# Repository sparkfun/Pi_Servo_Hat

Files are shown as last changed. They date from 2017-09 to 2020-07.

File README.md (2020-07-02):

SparkFun Pi Servo pHAT
=====================

Pi Servo pHAT (https://cdn.sparkfun.com/assets/parts/1/3/8/2/7/15316-SparkFun_Servo_pHAT_for_Raspberry_Pi-01.jpg)

[SparkFun Servo pHAT for Raspberry Pi (DEV-15316)](https://www.sparkfun.com/products/15316)

<!--
<table class="table table-hover table-striped table-bordered">
  <tr align="center">
   <td><a href="https://www.sparkfun.com/products/14328"><img src="https://cdn.sparkfun.com/r/600-600/assets/parts/1/2/3/0/2/14328-01.jpg" alt="Pi Servo Hat"></a></td>
   <td><a href="https://www.sparkfun.com/products/14329"><img src="https://cdn.sparkfun.com/r/600-600/assets/parts/1/2/3/0/3/Pi-Cam_Kit_14329-_01.jpg" alt="SparkFun Raspberry Pi Zero W Camera Kit"></a></td>
  </tr>
  <tr align="center">
    <td><i>Pi Servo Hat [<a href="https://www.sparkfun.com/products/14328">DEV-14328</a>]</i></td>
    <td><i>SparkFun Raspberry Pi Zero W Camera Kit [<a href="https://www.sparkfun.com/products/14329">KIT-14329</a>]</i></td>
  </tr>
</table>
-->

The Pi Servo pHAT is a hat that adds, via I<sup>2</sup>C, the ability to control up to 16 servo motors with a Raspberry Pi. It is the same size and form factor as a Pi Zero or Pi Zero W. The Pi Servo pHAT is great for adding pan/tilt control with the Raspberry Pi Camera to create homemade motion-activated security systems, webcam interfaces for streaming, or monitoring stations for any number of projects and adventures. 

Repository Contents
-------------------
* **/Hardware** - All Eagle design files (.brd, .sch)
* **/Examples** - All Python examples for this board
* **/Production** - Test bed files and production panel files

Documentation
--------------
* **[Hookup Guide](https://learn.sparkfun.com/tutorials/pi-servo-phat-v2-hookup-guide)** - Basic hookup guide for the Pi Servo pHAT.
* **[Setting Up the Pi Zero Wireless Pan-Tilt Camera](https://learn.sparkfun.com/tutorials/setting-up-the-pi-zero-wireless-pan-tilt-camera)** - Pi Zero Wireless Pan-Tilt Camera Kit Assembly Guide (*can be used with the Pi Servo pHAT*). 

Product Versions
--------------
* [SparkFun Pi Servo HAT (DEV-14328)](https://www.sparkfun.com/products/14328) - Original product release.
* [SparkFun Pi Servo pHAT for Raspberry Pi (DEV-15316)](https://www.sparkfun.com/products/15316)- Updated USB-to-serial converter (CH340C) and USB-C connector, corrected to Pi HAT form factor, added QWiic connector and reverse current protection, provides 4-pin header for compatibility with Sphero RVR, and comes with pre-soldered female 40-pin GPIO header.

License Information
-------------------

This product is _**open source**_! 

Please review the LICENSE.md file for license information. 

If you have any questions or concerns on licensing, please visit the [SparkFun Forum](https://forum.sparkfun.com/index.php) and post a topic. <!--For more general questions related to our Raspberry Pi hats, please visit this section of the forum: [SparkFun Forums: Raspberry Pi Products](https://forum.sparkfun.com/viewforum.php?f=105)-->

Distributed as-is; no warranty is given.

- Your friends at SparkFun.

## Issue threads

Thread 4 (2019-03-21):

More than 16 servo motors

Neorichi, 2019-03-21:
Hi,
Thanks for this project but i am interesting about get more than 16 servo motors... could you help me?

Thanks a lot

edspark, 2019-03-21:
Hello!

This isn't an "issue" in the way Github issues are intended to be used. However, this is a great topic to bring up in the robotics page of our forums:

https://forum.sparkfun.com/viewforum.php?f=107&sid=6486982292d4ee408e5b5e12ff93be67

Closed 2019-03-21.

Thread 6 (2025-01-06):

Voltage levels

mrherman, 2025-01-06:
I haven't tried this hat yet, but confused how it is wired up.  The schematic shows the PCA9685 being powered from the 5V signal, but it then expects a 0.7 Vdd voltage or higher for the I2C.  Table 14 of the data sheet.  That is 3.5V, but the I2C line of the Pi is a 3.3V logic level.

Is this really powered via the 5V line?  Any issues with I2C not working periodically?

In addition it looks like the address lines are left floating?  The data sheet said they don't have internal pull up resistors on those pins, so they are truly floating?

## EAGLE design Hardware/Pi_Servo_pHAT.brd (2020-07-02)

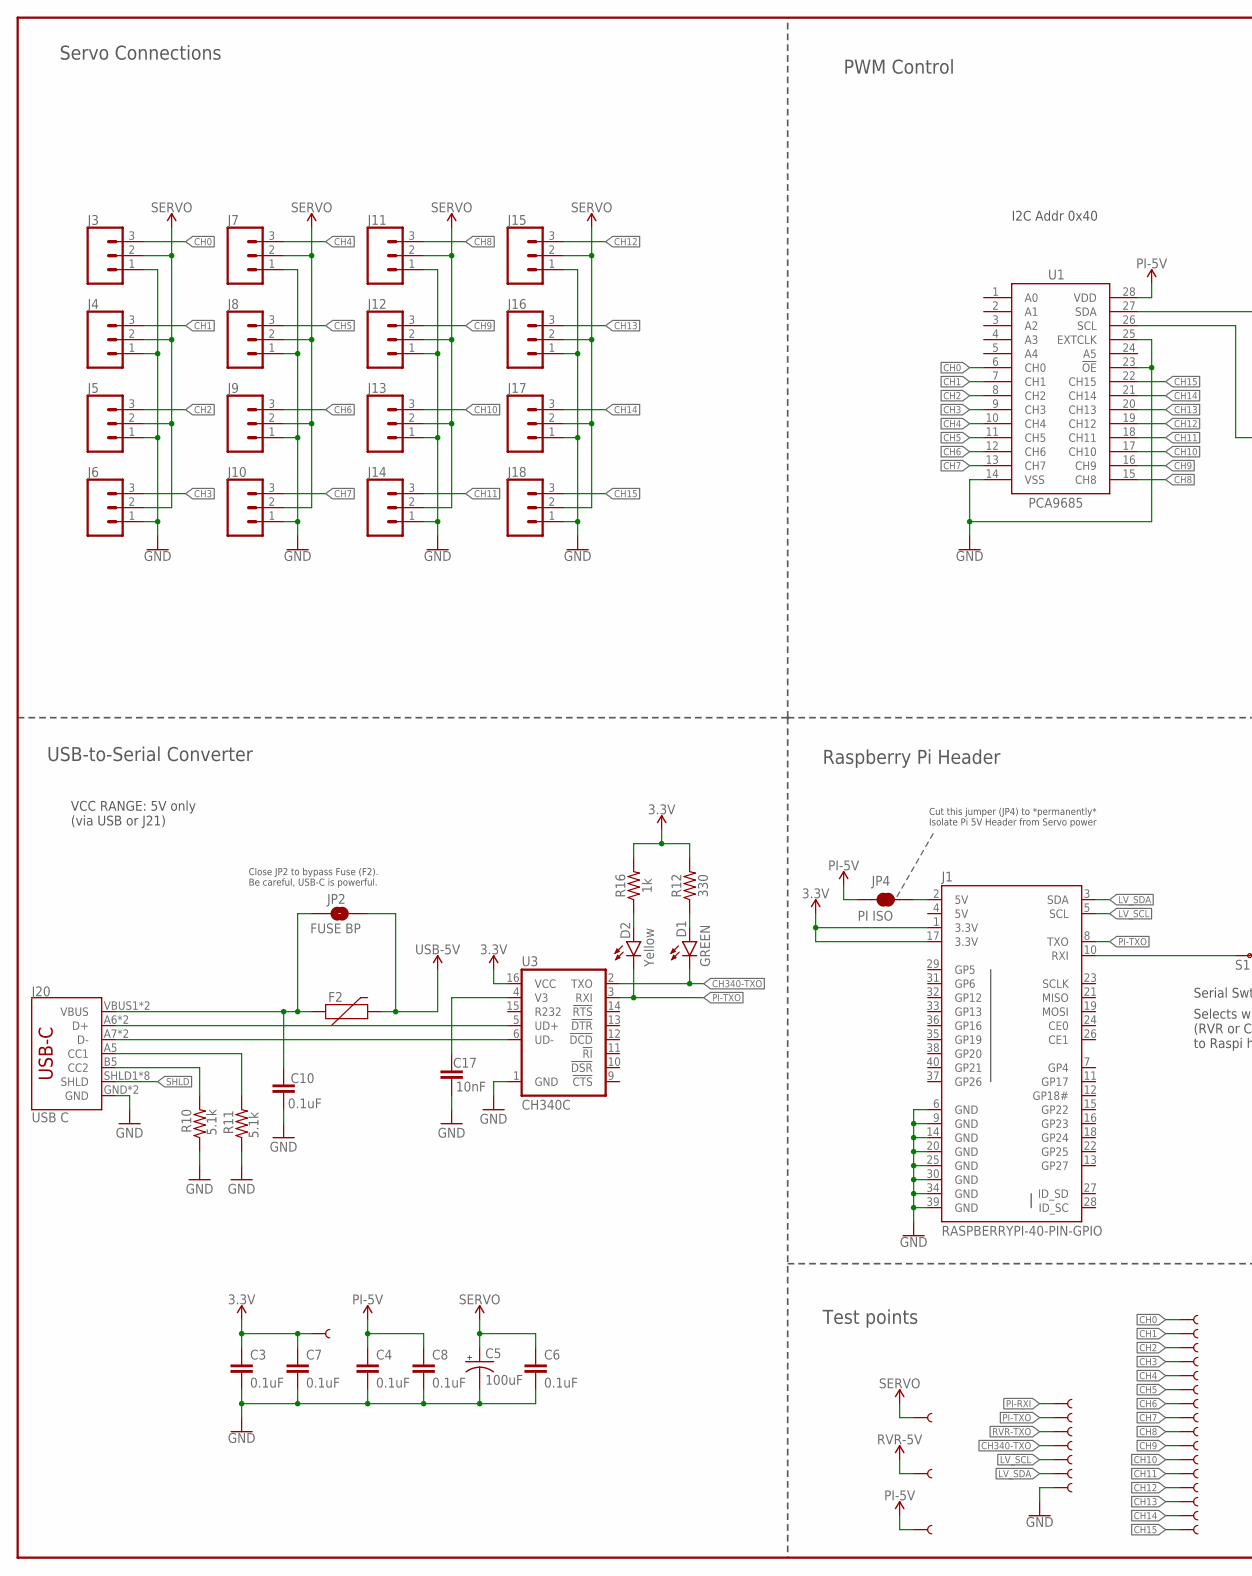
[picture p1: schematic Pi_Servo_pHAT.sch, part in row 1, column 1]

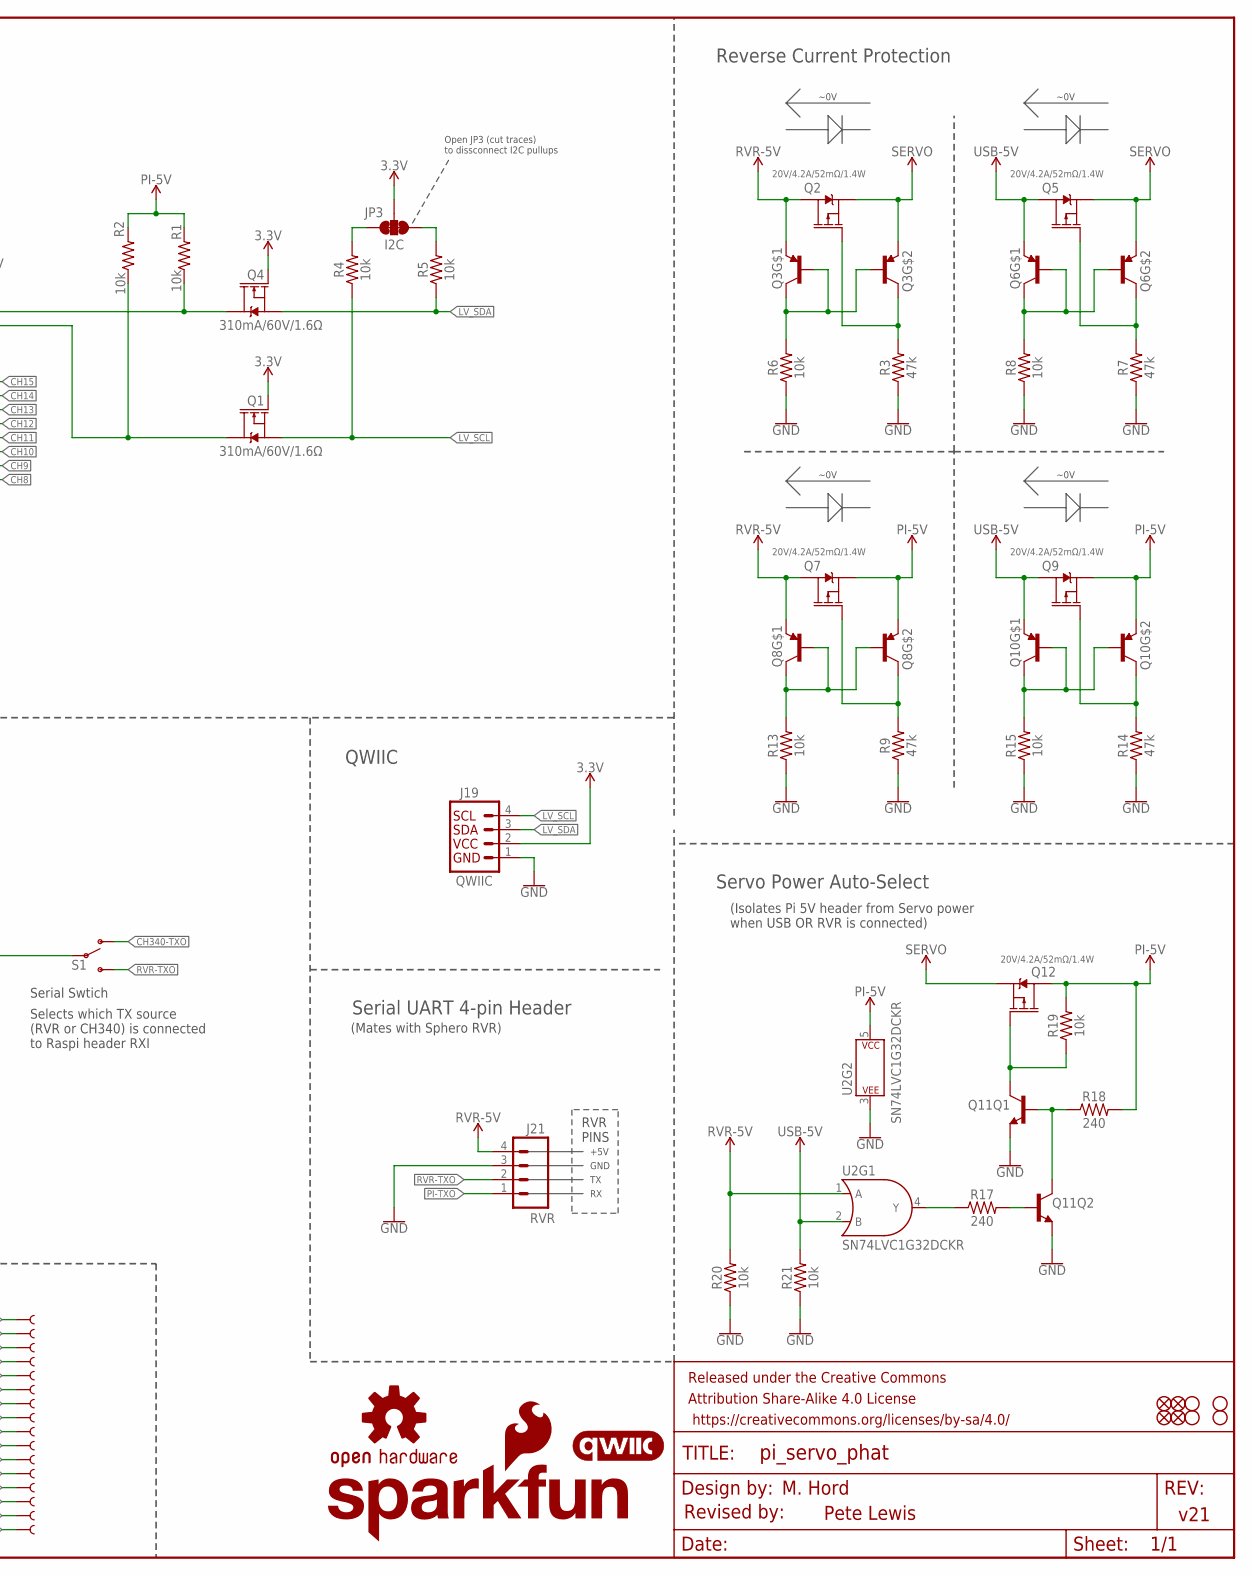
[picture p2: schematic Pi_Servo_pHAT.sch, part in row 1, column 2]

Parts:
C3, C4, C6, C7, C8, C10: 0.1uF; 0603
C5: 100uF; PANASONIC_D
C17: 10nF; 0603
D1: GREEN; LED-0603
D2: Yellow; LED-0603
F2: 16V/2.5A(5A TRIP); 1812
FD1, FD2, FD3, FD4: FIDUCIALUFIDUCIAL; FIDUCIAL-MICRO
FRAME2: FRAME-LEDGER; CREATIVE_COMMONS
H1, H2, H3, H4: STAND-OFF
J1: RASPBERRYPI-40-PIN-GPIO; 2X20
J3, J4, J5, J6, J7, J8, J9, J10, J11, J12, J13, J14, J15, J16, J17, J18: CONN_03; 1X03
J19: QWIIC; JST04_1MM_RA
J20: USB C; USB-C-16P
J21: RVR; 1X04_LOCK
JP2: FUSE BP; SMT-JUMPER_2_NO_SILK
JP3: I2C; SMT-JUMPER_3_2-NC_TRACE_SILK
JP4: PI ISO; SMT-JUMPER_2_NC_TRACE_SILK
LOGO1: SFE_LOGO_NAME_FLAME.1_INCH; SFE_LOGO_NAME_FLAME_.1
LOGO2: OSHW-LOGOS; OSHW-LOGO-S
Q1, Q4: 310mA/60V/1.6Ω; SOT323
Q2, Q5, Q7, Q9, Q12: 20V/4.2A/52mΩ/1.4W; SOT23-3
Q3, Q6, Q8, Q10: TRANS_PNP_DUALSOT-363; SOT363_PHILIPS
Q11: TRANS_NPN_DUAL-MBT3904DW1T1; SC70-6
R1, R2, R4, R5, R6, R8, R13, R15, R19, R20, R21: 10k; 0603
R3, R7, R9, R14: 47k; 0603
R10, R11: 5.1k; 0603
R12: 330; 0603
R16: 1k; 0603
R17, R18: 240; 0603
S1: SWITCH-SPDT-SMD-RIGHT-ANGLE; SWITCH_SPST_SMD_A
TP0, TP1, TP2, TP3, TP4, TP5, TP6, TP7, TP8, TP9, TP10, TP11, TP12, TP13, TP14, TP15, TP16, TP17, TP20, TP21, TP22, TP23, TP24, TP25, TP26: TEST-POINT3X4; PAD.03X.04
TP18, TP19: TEST-POINTTP_15TH_THRU; TP_15TH
U1: PCA9685; TSSOP-28_4MM
U2: SN74LVC1G32DCKR; SOT353
U3: CH340C; SO016
U$1: QWIIC_LOGO_5MM; QWIIC_5MM

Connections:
3.3V: C3.1, C7.1, J1.1 (3.3V), J1.17 (3.3V), J19.2, JP3.2, Q1.1 (G), Q4.1 (G), R12.2, R16.2, TP22.P$1, U3.16 (VCC)
5V: J1.4 (5V)
CC1: J20.A5 (CC1), R11.2
CC2: J20.B5 (CC2), R10.2
CH0: J3.3, TP0.P$1, U1.6 (CH0)
CH1: J4.3, TP1.P$1, U1.7 (CH1)
CH2: J5.3, TP2.P$1, U1.8 (CH2)
CH3: J6.3, TP3.P$1, U1.9 (CH3)
CH4: J7.3, TP4.P$1, U1.10 (CH4)
CH5: J8.3, TP5.P$1, U1.11 (CH5)
CH6: J9.3, TP6.P$1, U1.12 (CH6)
CH7: J10.3, TP7.P$1, U1.13 (CH7)
CH8: J11.3, TP8.P$1, U1.15 (CH8)
CH9: J12.3, TP9.P$1, U1.16 (CH9)
CH10: J13.3, TP10.P$1, U1.17 (CH10)
CH11: J14.3, TP11.P$1, U1.18 (CH11)
CH12: J15.3, TP12.P$1, U1.19 (CH12)
CH13: J16.3, TP13.P$1, U1.20 (CH13)
CH14: J17.3, TP14.P$1, U1.21 (CH14)
CH15: J18.3, TP15.P$1, U1.22 (CH15)
CH340-TXO: D1.C, S1.1 (O), TP23.P$1, U3.2 (TXO)
D+: J20.A6 (D+), J20.B6 (D+), U3.5 (UD+)
D-: J20.A7 (D-), J20.B7 (D-), U3.6 (UD-)
GND: C3.2, C4.2, C5.-, C6.2, C7.2, C8.2, C10.2, C17.2, J1.6 (GND), J1.9 (GND), J1.14 (GND), J1.20 (GND), J1.25 (GND), J1.30 (GND), J1.34 (GND), J1.39 (GND), J3.1, J4.1, J5.1, J6.1, J7.1, J8.1, J9.1, J10.1, J11.1, J12.1, J13.1, J14.1, J15.1, J16.1, J17.1, J18.1, J19.1, J20.GND, J20.GND2 (GND), J21.3, Q11.1 (E), Q11.4 (E), R3.1, R6.1, R7.1, R8.1, R9.1, R10.1, R11.1, R13.1, R14.1, R15.1, R20.1, R21.1, TP17.P$1, U1.14 (VSS), U1.23 (!OE), U1.25 (EXTCLK), U2.3 (P$V-), U3.1 (GND)
LV_SCL: J1.5 (SCL), J19.4, Q1.2 (S), R4.1, TP18.P$1
LV_SDA: J1.3 (SDA), J19.3, Q4.2 (S), R5.1, TP19.P$1
unnamed: Q5.1 (G), Q6.3 (C), R7.2
unnamed: JP3.3, R4.2
unnamed: Q1.3 (D), R2.1, U1.26 (SCL)
unnamed: Q4.3 (D), R1.1, U1.27 (SDA)
unnamed: JP3.1, R5.2
unnamed: D2.A, R16.1
unnamed: D1.A, R12.1
unnamed: Q11.2 (B), R17.2
unnamed: Q2.1 (G), Q3.3 (C), R3.2
unnamed: Q3.2 (B), Q3.5 (B), Q3.6 (C), R6.2
unnamed: Q6.2 (B), Q6.5 (B), Q6.6 (C), R8.2
unnamed: Q11.5 (B), Q11.6 (C), R18.1
unnamed: Q11.3 (C), Q12.1 (G), R19.1
unnamed: C17.1, U3.4 (V3)
unnamed: Q7.1 (G), Q8.3 (C), R9.2
unnamed: Q8.2 (B), Q8.5 (B), Q8.6 (C), R13.2
unnamed: R17.1, U2.4 (Y)
unnamed: Q9.1 (G), Q10.3 (C), R14.2
unnamed: Q10.2 (B), Q10.5 (B), Q10.6 (C), R15.2
unnamed: J1.2 (5V), JP4.2
PI-5V: C4.1, C8.1, JP4.1, Q7.2 (S), Q8.4 (E), Q9.2 (S), Q10.4 (E), Q12.3 (D), R1.2, R2.2, R18.2, R19.2, TP24.P$1, U1.28 (VDD), U2.5 (P$V+)
PI-RXI: J1.10 (RXI), S1.2, TP26.P$1
PI-TXO: D2.C, J1.8 (TXO), J21.1, TP20.P$1, U3.3 (RXI)
RVR-5V: J21.4, Q2.3 (D), Q3.1 (E), Q7.3 (D), Q8.1 (E), R20.2, TP25.P$1, U2.1 (A)
RVR-TXO: J21.2, S1.3 (S), TP21.P$1
SERVO: C5.+, C6.1, J3.2, J4.2, J5.2, J6.2, J7.2, J8.2, J9.2, J10.2, J11.2, J12.2, J13.2, J14.2, J15.2, J16.2, J17.2, J18.2, Q2.2 (S), Q3.4 (E), Q5.2 (S), Q6.4 (E), Q12.2 (S), TP16.P$1
SHLD: J20.SHLD1 (SHLD), J20.SHLD2 (SHLD), J20.SHLD3 (SHLD), J20.SHLD4 (SHLD), J20.SHLD5 (SHLD), J20.SHLD6 (SHLD), J20.SHLD7 (SHLD), J20.SHLD8 (SHLD)
USB-5V: F2.2, JP2.2, Q5.3 (D), Q6.1 (E), Q9.3 (D), Q10.1 (E), R21.2, U2.2 (B)
VBUS: C10.1, F2.1, J20.VBUS1 (VBUS), J20.VBUS2 (VBUS), JP2.1

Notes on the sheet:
M. Hord
v21
Raspberry Pi Header
PWM Control
Servo Connections
Cut this jumper (JP4) to *permanently* Isolate Pi 5V Header from Servo power
I2C Addr 0x40
Revised by:
Pete Lewis
USB-to-Serial Converter
Close JP2 to bypass Fuse (F2). Be careful, USB-C is powerful.
Serial UART 4-pin Header
(Mates with Sphero RVR)
Open JP3 (cut traces) to dissconnect I2C pullups
VCC RANGE: 5V only (via USB or J21)
~0V
Serial Swtich
Selects which TX source (RVR or CH340) is connected to Raspi header RXI
QWIIC
Servo Power Auto-Select
Reverse Current Protection
(Isolates Pi 5V header from Servo power when USB OR RVR is connected)
Test points
RVR PINS
+5V
GND

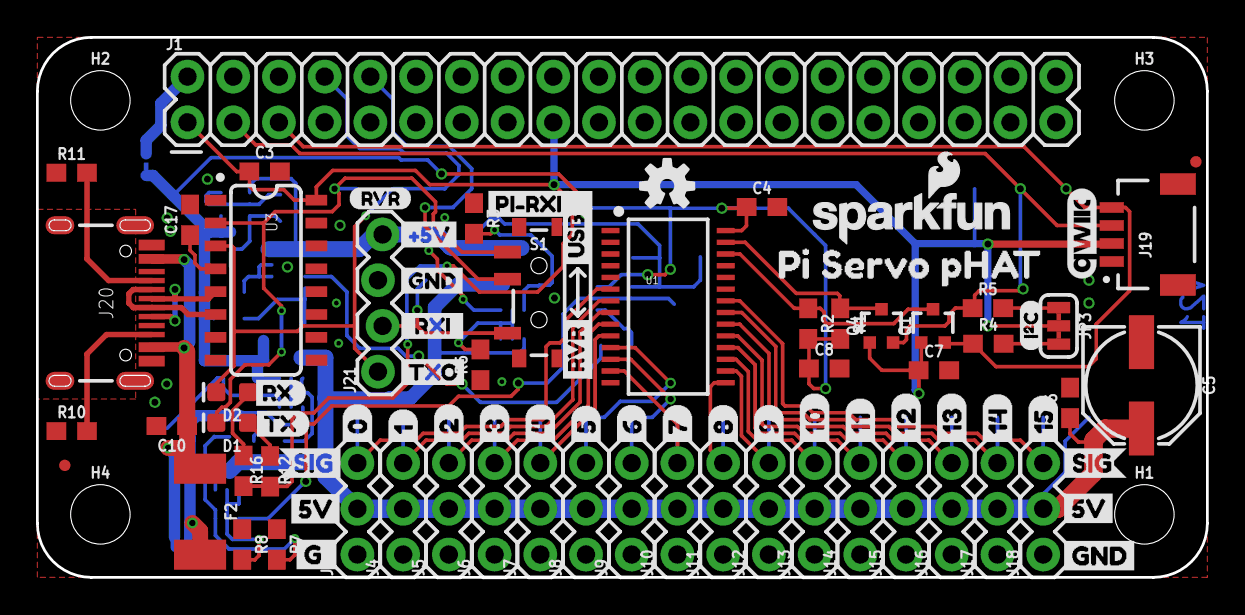
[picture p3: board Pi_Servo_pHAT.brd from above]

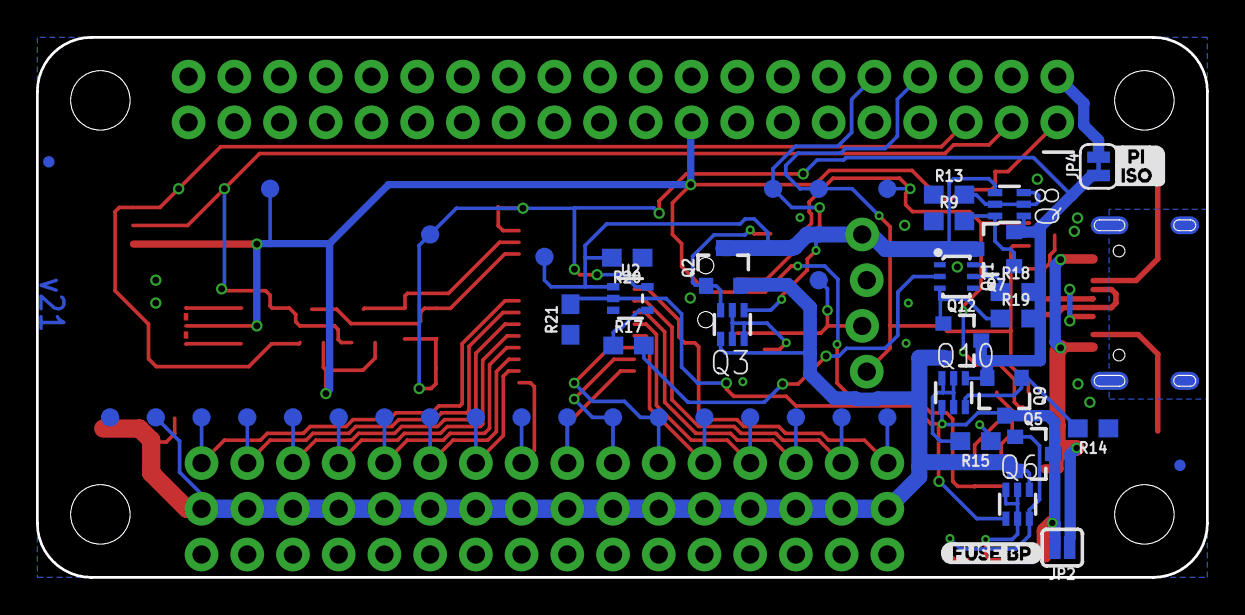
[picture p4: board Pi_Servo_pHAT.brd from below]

Board: 2 copper layers, 65.0 x 30.0 mm, 148 parts (52 on the bottom side), 54 nets.

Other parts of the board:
U$2: I_SUPER2_C-()-03
U$3: 028
U$4: 129
U$5: 230
U$6: 331
U$7: 432
U$8: 533
U$9: 634
U$10: 735
U$11: 836
U$12: 937
U$13: 1038
U$14: 1139
U$15: 1240
U$16: 1341
U$17: 1442
U$18: 1543
U$20, U$24: 5V5
U$21: SIG2
U$22: SIG3
U$23: GND25
U$25: TXO0
U$26: PI#RXI2
U$27: #5V3
U$28: GND2
U$30: RASP_μPI_HAT_SPECIFICATION
U$31: RVR1
U$32: ISO1
U$33: _RXI_0
U$34: USB0
U$35: PI0
U$36: RX0
U$37: TX1
U$38: RVR0
U$39: FUSE_BP0
U$40: G_0
U$41: PI_SERVO_PHAT0

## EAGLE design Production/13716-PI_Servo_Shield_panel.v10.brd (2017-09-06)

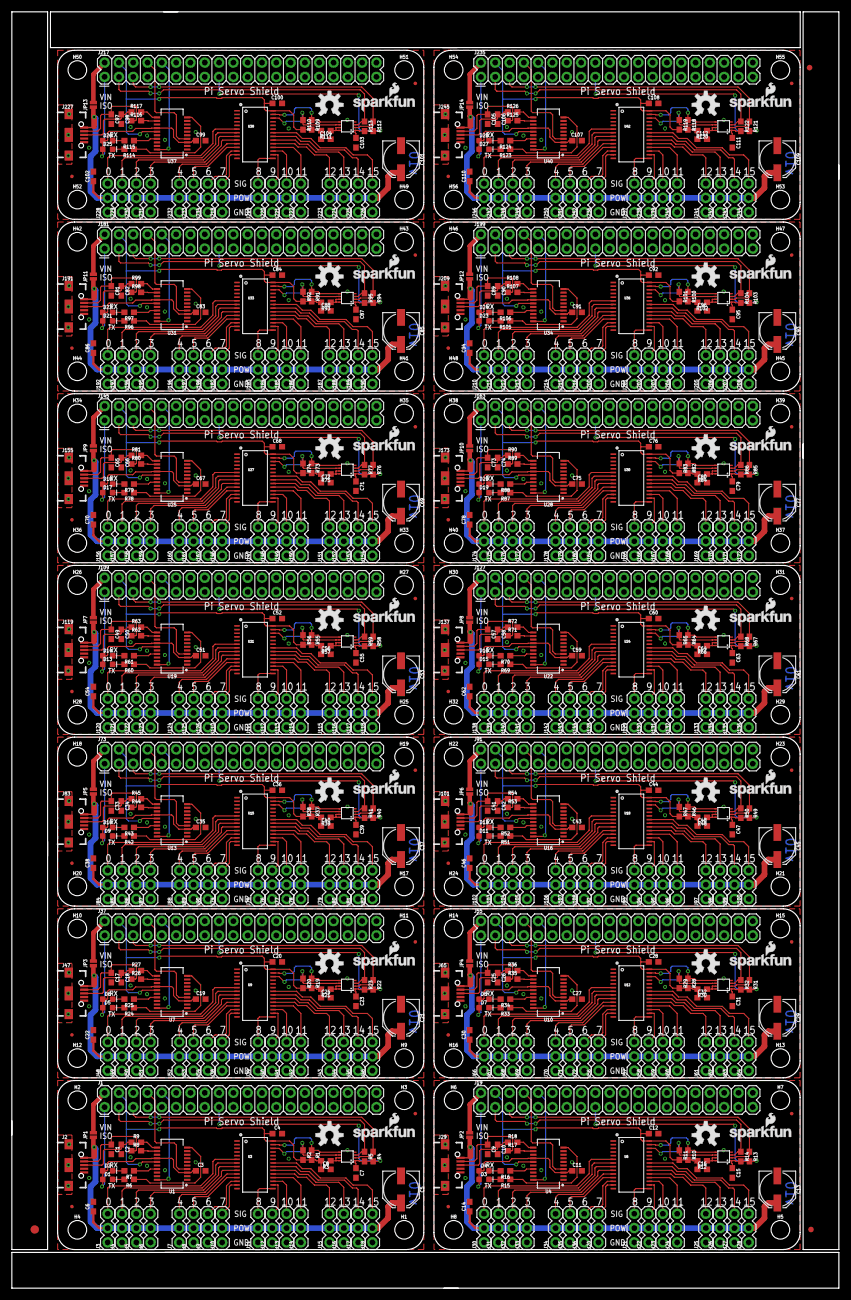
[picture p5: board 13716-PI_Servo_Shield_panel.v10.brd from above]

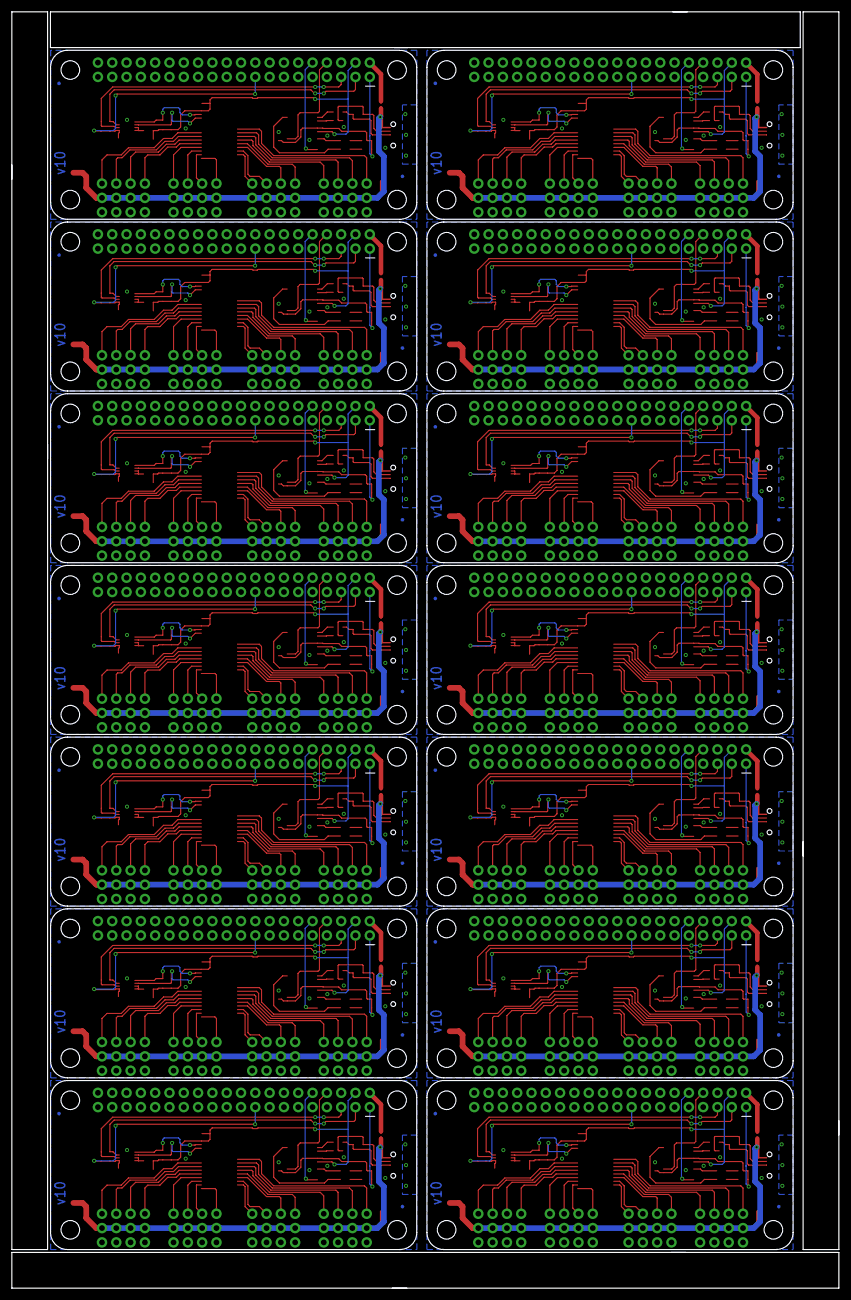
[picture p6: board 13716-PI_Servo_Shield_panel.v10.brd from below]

Board: 2 copper layers, 146.8 x 226.6 mm, 717 parts (28 on the bottom side), 532 nets.

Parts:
C1, C2, C9, C10, C17, C18, C25, C26, C33, C34, C41, C42, C49, C50, C57, C58, C65, C66, C73, C74, C81, C82, C89, C90, C97, C98, C105, C106: 47pF; 0603
C3, C4, C6, C7, C8, C11, C12, C14, C15, C16, C19, C20, C22, C23, C24, C27, C28, C30, C31, C32, C35, C36, C38, C39, C40, C43, C44, C46, C47, C48, C51, C52, C54, C55, C56, C59, C60, C62, C63, C64, C67, C68, C70, C71, C72, C75, C76, C78, C79, C80, C83, C84, C86, C87, C88, C91, C92, C94, C95, C96, C99, C100, C102, C103, C104, C107, C108, C110, C111, C112: 0.1uF; 0603
C5, C13, C21, C29, C37, C45, C53, C61, C69, C77, C85, C93, C101, C109: 100uF; PANASONIC_D
D1, D3, D5, D7, D9, D11, D13, D15, D17, D19, D21, D23, D25, D27: GREEN; LED-0603
D2, D4, D6, D8, D10, D12, D14, D16, D18, D20, D22, D24, D26, D28: Yellow; LED-0603
E$1: FIDUCIAL-1.5X3
E$7, E$8: FIDUCIAL-1X2
FD1, FD2, FD3, FD4, FD5, FD6, FD7, FD8, FD9, FD10, FD11, FD12, FD13, FD14, FD15, FD16, FD17, FD18, FD19, FD20, FD21, FD22, FD23, FD24, FD25, FD26, FD27, FD28, FD29, FD30, FD31, FD32, FD33, FD34, FD35, FD36, FD37, FD38, FD39, FD40, FD41, FD42, FD43, FD44, FD45, FD46, FD47, FD48, FD49, FD50, FD51, FD52, FD53, FD54, FD55, FD56: FIDUCIALUFIDUCIAL; FIDUCIAL-MICRO
H1, H2, H3, H4, H5, H6, H7, H8, H9, H10, H11, H12, H13, H14, H15, H16, H17, H18, H19, H20, H21, H22, H23, H24, H25, H26, H27, H28, H29, H30, H31, H32, H33, H34, H35, H36, H37, H38, H39, H40, H41, H42, H43, H44, H45, H46, H47, H48, H49, H50, H51, H52, H53, H54, H55, H56: STAND-OFF
J1, J19, J37, J55, J73, J91, J109, J127, J145, J163, J181, J199, J217, J235: RASPBERRYPI-40-PIN-GPIO_PTH_NO_SHROUD; 2X20
J2, J29, J47, J65, J83, J101, J119, J137, J155, J173, J191, J209, J227, J245: USB-B-MICRO-SMD
J3, J4, J5, J6, J7, J8, J9, J10, J11, J12, J13, J14, J15, J16, J17, J18, J20, J21, J22, J23, J24, J25, J26, J27, J28, J30, J31, J32, J33, J34, J35, J36, J38, J39, J40, J41, J42, J43, J44, J45, J46, J48, J49, J50, J51, J52, J53, J54, J56, J57, J58, J59, J60, J61, J62, J63, J64, J66, J67, J68, J69, J70, J71, J72, J74, J75, J76, J77, J78, J79, J80, J81, J82, J84, J85, J86, J87, J88, J89, J90, J92, J93, J94, J95, J96, J97, J98, J99, J100, J102, J103, J104, J105, J106, J107, J108, J110, J111, J112, J113, J114, J115, J116, J117, J118, J120, J121, J122, J123, J124, J125, J126, J128, J129, J130, J131, J132, J133, J134, J135, J136, J138, J139, J140, J141, J142, J143, J144, J146, J147, J148, J149, J150, J151, J152, J153, J154, J156, J157, J158, J159, J160, J161, J162, J164, J165, J166, J167, J168, J169, J170, J171, J172, J174, J175, J176, J177, J178, J179, J180, J182, J183, J184, J185, J186, J187, J188, J189, J190, J192, J193, J194, J195, J196, J197, J198, J200, J201, J202, J203, J204, J205, J206, J207, J208, J210, J211, J212, J213, J214, J215, J216, J218, J219, J220, J221, J222, J223, J224, J225, J226, J228, J229, J230, J231, J232, J233, J234, J236, J237, J238, J239, J240, J241, J242, J243, J244, J246, J247, J248, J249, J250, J251, J252: 1X03
JP1, JP2, JP3, JP4, JP5, JP6, JP7, JP8, JP9, JP10, JP11, JP12, JP13, JP14: JUMPER-SMT_2_NC_PASTE_NO-SILK; SMT-JUMPER_2_NC_PASTE_NO-SILK
LOGO1, LOGO3, LOGO5, LOGO7, LOGO9, LOGO11, LOGO13, LOGO15, LOGO17, LOGO19, LOGO21, LOGO23, LOGO25, LOGO27: SFE_LOGO_NAME_FLAME.1_INCH; SFE_LOGO_NAME_FLAME_.1
LOGO2, LOGO4, LOGO6, LOGO8, LOGO10, LOGO12, LOGO14, LOGO16, LOGO18, LOGO20, LOGO22, LOGO24, LOGO26, LOGO28: OSHW-LOGOM; OSHW-LOGO-M
R1, R2, R4, R5, R10, R11, R13, R14, R19, R20, R22, R23, R28, R29, R31, R32, R37, R38, R40, R41, R46, R47, R49, R50, R55, R56, R58, R59, R64, R65, R67, R68, R73, R74, R76, R77, R82, R83, R85, R86, R91, R92, R94, R95, R100, R101, R103, R104, R109, R110, R112, R113, R118, R119, R121, R122: 10k; 0603
R3, R12, R21, R30, R39, R48, R57, R66, R75, R84, R93, R102, R111, R120: 200k; 0603
R6, R7, R15, R16, R24, R25, R33, R34, R42, R43, R51, R52, R60, R61, R69, R70, R78, R79, R87, R88, R96, R97, R105, R106, R114, R115, R123, R124: 1k; 0603
R8, R9, R17, R18, R26, R27, R35, R36, R44, R45, R53, R54, R62, R63, R71, R72, R80, R81, R89, R90, R98, R99, R107, R108, R116, R117, R125, R126: 27; 0603
U1, U4, U7, U10, U13, U16, U19, U22, U25, U28, U31, U34, U37, U40: FT231XS; SSOP20_L
U2, U5, U8, U11, U14, U17, U20, U23, U26, U29, U32, U35, U38, U41: PCA9306; PSOP-8
U3, U6, U9, U12, U15, U18, U21, U24, U27, U30, U33, U36, U39, U42: PCA9685; TSSOP-28_4MM

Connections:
3.3VA: C3.1, D1.A, D2.A, J1.1, U1.3, U1.14
3.3VA1: C11.1, D3.A, D4.A, J19.1, U4.3, U4.14
3.3VA2: C19.1, D5.A, D6.A, J37.1, U7.3, U7.14
3.3VA3: C27.1, D7.A, D8.A, J55.1, U10.3, U10.14
3.3VA4: C35.1, D9.A, D10.A, J73.1, U13.3, U13.14
3.3VA5: C43.1, D11.A, D12.A, J91.1, U16.3, U16.14
3.3VA6: C51.1, D13.A, D14.A, J109.1, U19.3, U19.14
3.3VA7: C59.1, D15.A, D16.A, J127.1, U22.3, U22.14
3.3VA8: C67.1, D17.A, D18.A, J145.1, U25.3, U25.14
3.3VA9: C75.1, D19.A, D20.A, J163.1, U28.3, U28.14
3.3VA10: C83.1, D21.A, D22.A, J181.1, U31.3, U31.14
3.3VA11: C91.1, D23.A, D24.A, J199.1, U34.3, U34.14
3.3VA12: C99.1, D25.A, D26.A, J217.1, U37.3, U37.14
3.3VA13: C107.1, D27.A, D28.A, J235.1, U40.3, U40.14
3.3VB: C7.1, J1.17, R4.2, R5.2, U2.1
3.3VB1: C15.1, J19.17, R13.2, R14.2, U5.1
3.3VB2: C23.1, J37.17, R22.2, R23.2, U8.1
3.3VB3: C31.1, J55.17, R31.2, R32.2, U11.1
3.3VB4: C39.1, J73.17, R40.2, R41.2, U14.1
3.3VB5: C47.1, J91.17, R49.2, R50.2, U17.1
3.3VB6: C55.1, J109.17, R58.2, R59.2, U20.1
3.3VB7: C63.1, J127.17, R67.2, R68.2, U23.1
3.3VB8: C71.1, J145.17, R76.2, R77.2, U26.1
3.3VB9: C79.1, J163.17, R85.2, R86.2, U29.1
3.3VB10: C87.1, J181.17, R94.2, R95.2, U32.1
3.3VB11: C95.1, J199.17, R103.2, R104.2, U35.1
3.3VB12: C103.1, J217.17, R112.2, R113.2, U38.1
3.3VB13: C111.1, J235.17, R121.2, R122.2, U41.1
5VA: J1.2, JP1.2
5VA1: J19.2, JP2.2
5VA2: J37.2, JP3.2
5VA3: J55.2, JP4.2
5VA4: J73.2, JP5.2
5VA5: J91.2, JP6.2
5VA6: J109.2, JP7.2
5VA7: J127.2, JP8.2
5VA8: J145.2, JP9.2
5VA9: J163.2, JP10.2
5VA10: J181.2, JP11.2
5VA11: J199.2, JP12.2
5VA12: J217.2, JP13.2
5VA13: J235.2, JP14.2
5VB: C4.1, C8.1, J1.4, R1.2, R2.2, R3.2, U1.15, U3.28
5VB1: C12.1, C16.1, J19.4, R10.2, R11.2, R12.2, U4.15, U6.28
5VB2: C20.1, C24.1, J37.4, R19.2, R20.2, R21.2, U7.15, U9.28
5VB3: C28.1, C32.1, J55.4, R28.2, R29.2, R30.2, U10.15, U12.28
5VB4: C36.1, C40.1, J73.4, R37.2, R38.2, R39.2, U13.15, U15.28
5VB5: C44.1, C48.1, J91.4, R46.2, R47.2, R48.2, U16.15, U18.28
5VB6: C52.1, C56.1, J109.4, R55.2, R56.2, R57.2, U19.15, U21.28
5VB7: C60.1, C64.1, J127.4, R64.2, R65.2, R66.2, U22.15, U24.28
5VB8: C68.1, C72.1, J145.4, R73.2, R74.2, R75.2, U25.15, U27.28
5VB9: C76.1, C80.1, J163.4, R82.2, R83.2, R84.2, U28.15, U30.28
5VB10: C84.1, C88.1, J181.4, R91.2, R92.2, R93.2, U31.15, U33.28
5VB11: C92.1, C96.1, J199.4, R100.2, R101.2, R102.2, U34.15, U36.28
5VB12: C100.1, C104.1, J217.4, R109.2, R110.2, R111.2, U37.15, U39.28
5VB13: C108.1, C112.1, J235.4, R118.2, R119.2, R120.2, U40.15, U42.28
CH0: J3.3, U3.6
CH1: J4.3, U3.7
CH2: J5.3, U3.8
CH3: J6.3, U3.9
CH4: J7.3, U3.10
CH5: J8.3, U3.11
CH6: J9.3, U3.12
CH7: J10.3, U3.13
CH8: J11.3, U3.15
CH9: J12.3, U3.16
CH10: J13.3, U3.17
CH11: J14.3, U3.18
CH12: J15.3, U3.19
CH13: J16.3, U3.20
CH14: J17.3, U3.21
CH15: J18.3, U3.22
CH16: J28.3, U6.22
CH17: J27.3, U6.21
CH18: J26.3, U6.20
CH19: J25.3, U6.19
CH20: J24.3, U6.18
CH21: J23.3, U6.17
CH22: J22.3, U6.16
CH23: J21.3, U6.15
CH24: J36.3, U6.12
CH25: J35.3, U6.11
CH26: J34.3, U6.10
CH27: J33.3, U6.9
CH28: J32.3, U6.8
CH29: J31.3, U6.7
CH30: J30.3, U6.6
CH31: J20.3, U6.13
CH32: J46.3, U9.22
CH33: J45.3, U9.21
CH34: J44.3, U9.20
CH35: J43.3, U9.19
CH36: J42.3, U9.18
CH37: J41.3, U9.17
CH38: J40.3, U9.16
CH39: J39.3, U9.15
CH40: J54.3, U9.12
CH41: J53.3, U9.11
CH42: J52.3, U9.10
CH43: J51.3, U9.9
CH44: J50.3, U9.8
CH45: J49.3, U9.7
CH46: J48.3, U9.6
CH47: J38.3, U9.13
CH48: J64.3, U12.22
CH49: J63.3, U12.21
CH50: J62.3, U12.20
CH51: J61.3, U12.19
CH52: J60.3, U12.18
CH53: J59.3, U12.17
CH54: J58.3, U12.16
CH55: J57.3, U12.15
CH56: J72.3, U12.12
CH57: J71.3, U12.11
CH58: J70.3, U12.10
CH59: J69.3, U12.9
CH60: J68.3, U12.8
CH61: J67.3, U12.7
CH62: J66.3, U12.6
CH63: J56.3, U12.13
CH64: J82.3, U15.22
CH65: J81.3, U15.21
CH66: J80.3, U15.20
CH67: J79.3, U15.19
CH68: J78.3, U15.18
CH69: J77.3, U15.17
CH70: J76.3, U15.16
CH71: J75.3, U15.15
CH72: J90.3, U15.12
CH73: J89.3, U15.11
CH74: J88.3, U15.10
CH75: J87.3, U15.9
CH76: J86.3, U15.8
CH77: J85.3, U15.7
CH78: J84.3, U15.6
CH79: J74.3, U15.13
CH80: J100.3, U18.22
CH81: J99.3, U18.21
CH82: J98.3, U18.20
CH83: J97.3, U18.19
CH84: J96.3, U18.18
CH85: J95.3, U18.17
CH86: J94.3, U18.16
CH87: J93.3, U18.15
CH88: J108.3, U18.12
CH89: J107.3, U18.11
CH90: J106.3, U18.10
CH91: J105.3, U18.9
CH92: J104.3, U18.8
CH93: J103.3, U18.7
CH94: J102.3, U18.6
CH95: J92.3, U18.13
CH96: J118.3, U21.22
CH97: J117.3, U21.21
CH98: J116.3, U21.20
CH99: J115.3, U21.19
CH100: J114.3, U21.18
CH101: J113.3, U21.17
CH102: J112.3, U21.16
CH103: J111.3, U21.15
CH104: J126.3, U21.12
CH105: J125.3, U21.11
CH106: J124.3, U21.10
CH107: J123.3, U21.9
CH108: J122.3, U21.8
CH109: J121.3, U21.7
CH110: J120.3, U21.6
CH111: J110.3, U21.13
CH112: J136.3, U24.22
CH113: J135.3, U24.21
CH114: J134.3, U24.20
CH115: J133.3, U24.19
CH116: J132.3, U24.18
CH117: J131.3, U24.17
CH118: J130.3, U24.16
CH119: J129.3, U24.15
CH120: J144.3, U24.12
CH121: J143.3, U24.11
CH122: J142.3, U24.10
CH123: J141.3, U24.9
CH124: J140.3, U24.8
CH125: J139.3, U24.7
CH126: J138.3, U24.6
CH127: J128.3, U24.13
CH128: J154.3, U27.22
CH129: J153.3, U27.21
CH130: J152.3, U27.20
CH131: J151.3, U27.19
CH132: J150.3, U27.18
CH133: J149.3, U27.17
CH134: J148.3, U27.16
CH135: J147.3, U27.15
CH136: J162.3, U27.12
CH137: J161.3, U27.11
CH138: J160.3, U27.10
CH139: J159.3, U27.9
CH140: J158.3, U27.8
CH141: J157.3, U27.7
CH142: J156.3, U27.6
CH143: J146.3, U27.13
CH144: J172.3, U30.22
CH145: J171.3, U30.21
CH146: J170.3, U30.20
CH147: J169.3, U30.19
CH148: J168.3, U30.18
CH149: J167.3, U30.17
CH150: J166.3, U30.16
CH151: J165.3, U30.15
CH152: J180.3, U30.12
CH153: J179.3, U30.11
CH154: J178.3, U30.10
CH155: J177.3, U30.9
CH156: J176.3, U30.8
CH157: J175.3, U30.7
CH158: J174.3, U30.6
CH159: J164.3, U30.13
CH160: J190.3, U33.22
CH161: J189.3, U33.21
CH162: J188.3, U33.20
CH163: J187.3, U33.19
CH164: J186.3, U33.18
CH165: J185.3, U33.17
CH166: J184.3, U33.16
CH167: J183.3, U33.15
CH168: J198.3, U33.12
CH169: J197.3, U33.11
CH170: J196.3, U33.10
CH171: J195.3, U33.9
CH172: J194.3, U33.8
CH173: J193.3, U33.7
CH174: J192.3, U33.6
CH175: J182.3, U33.13
CH176: J208.3, U36.22
CH177: J207.3, U36.21
CH178: J206.3, U36.20
CH179: J205.3, U36.19
CH180: J204.3, U36.18
CH181: J203.3, U36.17
CH182: J202.3, U36.16
CH183: J201.3, U36.15
CH184: J216.3, U36.12
CH185: J215.3, U36.11
CH186: J214.3, U36.10
CH187: J213.3, U36.9
CH188: J212.3, U36.8
CH189: J211.3, U36.7
CH190: J210.3, U36.6
CH191: J200.3, U36.13
CH192: J226.3, U39.22
CH193: J225.3, U39.21
CH194: J224.3, U39.20
CH195: J223.3, U39.19
CH196: J222.3, U39.18
CH197: J221.3, U39.17
CH198: J220.3, U39.16
CH199: J219.3, U39.15
CH200: J234.3, U39.12
CH201: J233.3, U39.11
CH202: J232.3, U39.10
CH203: J231.3, U39.9
CH204: J230.3, U39.8
CH205: J229.3, U39.7
CH206: J228.3, U39.6
CH207: J218.3, U39.13
CH208: J244.3, U42.22
CH209: J243.3, U42.21
CH210: J242.3, U42.20
CH211: J241.3, U42.19
CH212: J240.3, U42.18
CH213: J239.3, U42.17
CH214: J238.3, U42.16
CH215: J237.3, U42.15
CH216: J252.3, U42.12
CH217: J251.3, U42.11
CH218: J250.3, U42.10
CH219: J249.3, U42.9
CH220: J248.3, U42.8
CH221: J247.3, U42.7
CH222: J246.3, U42.6
CH223: J236.3, U42.13
GND: C1.2, C2.2, C3.2, C4.2, C5.-, C6.2, C7.2, C8.2, J1.6, J1.9, J1.14, J1.20, J1.25, J1.30, J1.34, J1.39, J2.GND, J3.1, J4.1, J5.1, J6.1, J7.1, J8.1, J9.1, J10.1, J11.1, J12.1, J13.1, J14.1, J15.1, J16.1, J17.1, J18.1, U1.6, U1.16, U2.4, U3.14, U3.23, U3.25
GND1: C9.2, C10.2, C11.2, C12.2, C13.-, C14.2, C15.2, C16.2, J19.6, J19.9, J19.14, J19.20, J19.25, J19.30, J19.34, J19.39, J20.1, J21.1, J22.1, J23.1, J24.1, J25.1, J26.1, J27.1, J28.1, J29.GND, J30.1, J31.1, J32.1, J33.1, J34.1, J35.1, J36.1, U4.6, U4.16, U5.4, U6.14, U6.23, U6.25
GND2: C17.2, C18.2, C19.2, C20.2, C21.-, C22.2, C23.2, C24.2, J37.6, J37.9, J37.14, J37.20, J37.25, J37.30, J37.34, J37.39, J38.1, J39.1, J40.1, J41.1, J42.1, J43.1, J44.1, J45.1, J46.1, J47.GND, J48.1, J49.1, J50.1, J51.1, J52.1, J53.1, J54.1, U7.6, U7.16, U8.4, U9.14, U9.23, U9.25
GND3: C25.2, C26.2, C27.2, C28.2, C29.-, C30.2, C31.2, C32.2, J55.6, J55.9, J55.14, J55.20, J55.25, J55.30, J55.34, J55.39, J56.1, J57.1, J58.1, J59.1, J60.1, J61.1, J62.1, J63.1, J64.1, J65.GND, J66.1, J67.1, J68.1, J69.1, J70.1, J71.1, J72.1, U10.6, U10.16, U11.4, U12.14, U12.23, U12.25
GND4: C33.2, C34.2, C35.2, C36.2, C37.-, C38.2, C39.2, C40.2, J73.6, J73.9, J73.14, J73.20, J73.25, J73.30, J73.34, J73.39, J74.1, J75.1, J76.1, J77.1, J78.1, J79.1, J80.1, J81.1, J82.1, J83.GND, J84.1, J85.1, J86.1, J87.1, J88.1, J89.1, J90.1, U13.6, U13.16, U14.4, U15.14, U15.23, U15.25
GND5: C41.2, C42.2, C43.2, C44.2, C45.-, C46.2, C47.2, C48.2, J91.6, J91.9, J91.14, J91.20, J91.25, J91.30, J91.34, J91.39, J92.1, J93.1, J94.1, J95.1, J96.1, J97.1, J98.1, J99.1, J100.1, J101.GND, J102.1, J103.1, J104.1, J105.1, J106.1, J107.1, J108.1, U16.6, U16.16, U17.4, U18.14, U18.23, U18.25
GND6: C49.2, C50.2, C51.2, C52.2, C53.-, C54.2, C55.2, C56.2, J109.6, J109.9, J109.14, J109.20, J109.25, J109.30, J109.34, J109.39, J110.1, J111.1, J112.1, J113.1, J114.1, J115.1, J116.1, J117.1, J118.1, J119.GND, J120.1, J121.1, J122.1, J123.1, J124.1, J125.1, J126.1, U19.6, U19.16, U20.4, U21.14, U21.23, U21.25
GND7: C57.2, C58.2, C59.2, C60.2, C61.-, C62.2, C63.2, C64.2, J127.6, J127.9, J127.14, J127.20, J127.25, J127.30, J127.34, J127.39, J128.1, J129.1, J130.1, J131.1, J132.1, J133.1, J134.1, J135.1, J136.1, J137.GND, J138.1, J139.1, J140.1, J141.1, J142.1, J143.1, J144.1, U22.6, U22.16, U23.4, U24.14, U24.23, U24.25
GND8: C65.2, C66.2, C67.2, C68.2, C69.-, C70.2, C71.2, C72.2, J145.6, J145.9, J145.14, J145.20, J145.25, J145.30, J145.34, J145.39, J146.1, J147.1, J148.1, J149.1, J150.1, J151.1, J152.1, J153.1, J154.1, J155.GND, J156.1, J157.1, J158.1, J159.1, J160.1, J161.1, J162.1, U25.6, U25.16, U26.4, U27.14, U27.23, U27.25
GND9: C73.2, C74.2, C75.2, C76.2, C77.-, C78.2, C79.2, C80.2, J163.6, J163.9, J163.14, J163.20, J163.25, J163.30, J163.34, J163.39, J164.1, J165.1, J166.1, J167.1, J168.1, J169.1, J170.1, J171.1, J172.1, J173.GND, J174.1, J175.1, J176.1, J177.1, J178.1, J179.1, J180.1, U28.6, U28.16, U29.4, U30.14, U30.23, U30.25
GND10: C81.2, C82.2, C83.2, C84.2, C85.-, C86.2, C87.2, C88.2, J181.6, J181.9, J181.14, J181.20, J181.25, J181.30, J181.34, J181.39, J182.1, J183.1, J184.1, J185.1, J186.1, J187.1, J188.1, J189.1, J190.1, J191.GND, J192.1, J193.1, J194.1, J195.1, J196.1, J197.1, J198.1, U31.6, U31.16, U32.4, U33.14, U33.23, U33.25
GND11: C89.2, C90.2, C91.2, C92.2, C93.-, C94.2, C95.2, C96.2, J199.6, J199.9, J199.14, J199.20, J199.25, J199.30, J199.34, J199.39, J200.1, J201.1, J202.1, J203.1, J204.1, J205.1, J206.1, J207.1, J208.1, J209.GND, J210.1, J211.1, J212.1, J213.1, J214.1, J215.1, J216.1, U34.6, U34.16, U35.4, U36.14, U36.23, U36.25
GND12: C97.2, C98.2, C99.2, C100.2, C101.-, C102.2, C103.2, C104.2, J217.6, J217.9, J217.14, J217.20, J217.25, J217.30, J217.34, J217.39, J218.1, J219.1, J220.1, J221.1, J222.1, J223.1, J224.1, J225.1, J226.1, J227.GND, J228.1, J229.1, J230.1, J231.1, J232.1, J233.1, J234.1, U37.6, U37.16, U38.4, U39.14, U39.23, U39.25
GND13: C105.2, C106.2, C107.2, C108.2, C109.-, C110.2, C111.2, C112.2, J235.6, J235.9, J235.14, J235.20, J235.25, J235.30, J235.34, J235.39, J236.1, J237.1, J238.1, J239.1, J240.1, J241.1, J242.1, J243.1, J244.1, J245.GND, J246.1, J247.1, J248.1, J249.1, J250.1, J251.1, J252.1, U40.6, U40.16, U41.4, U42.14, U42.23, U42.25
LV_SCL: J1.5, R4.1, U2.2
LV_SCL1: J19.5, R13.1, U5.2
LV_SCL2: J37.5, R22.1, U8.2
LV_SCL3: J55.5, R31.1, U11.2
LV_SCL4: J73.5, R40.1, U14.2
LV_SCL5: J91.5, R49.1, U17.2
LV_SCL6: J109.5, R58.1, U20.2
LV_SCL7: J127.5, R67.1, U23.2
LV_SCL8: J145.5, R76.1, U26.2
LV_SCL9: J163.5, R85.1, U29.2
LV_SCL10: J181.5, R94.1, U32.2
LV_SCL11: J199.5, R103.1, U35.2
LV_SCL12: J217.5, R112.1, U38.2
LV_SCL13: J235.5, R121.1, U41.2
LV_SDA: J1.3, R5.1, U2.3
LV_SDA1: J19.3, R14.1, U5.3
LV_SDA2: J37.3, R23.1, U8.3
LV_SDA3: J55.3, R32.1, U11.3
LV_SDA4: J73.3, R41.1, U14.3
LV_SDA5: J91.3, R50.1, U17.3
LV_SDA6: J109.3, R59.1, U20.3
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

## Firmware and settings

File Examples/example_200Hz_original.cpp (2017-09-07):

#include <unistd.h> // required for I2C device access and usleep()
#include <fcntl.h>  // required for I2C device configuration
#include <sys/ioctl.h> // required for I2C device usage
#include <linux/i2c-dev.h> // required for constant definitions
#include <stdio.h>  // required for printf statements

int main(void)
{
  char *filename = (char*)"/dev/i2c-1"; // Define the filename
  int file_i2c = open(filename, O_RDWR); // open file for R/W

  if (file_i2c < 0)
  {
    printf("Failed to open file!");
    return -1;
  }

  int addr = 0x40;    // PCA9685 address
  ioctl(file_i2c, I2C_SLAVE, addr); // Set the I2C address for upcoming
                                    //  transactions

  char buffer[5];   // Create a buffer for transferring data to the I2C device

  // First we need to enable the chip. We do this by writing 0x20 to register
  //  0. buffer[0] is always the register address, and subsequent bytes are
  //  written out in order.
  buffer[0] = 0;    // target register
  buffer[1] = 0x20; // desired value
  int length = 2;       // number of bytes, including address
  write(file_i2c, buffer, length); // initiate write

  // Enable multi-byte writing.

  buffer[0] = 0xfe;  
  buffer[1] = 0x1e;
  write(file_i2c, buffer, length);

  // Write the start time out to the chip. This is the time when the chip will
  //  generate a high output.

  buffer[0] = 0x06;  // "start time" reg for channel 0
  buffer[1] = 0;     // We want the pulse to start at time t=0
  buffer[2] = 0;
  length = 3;        // 3 bytes total written
  write(file_i2c, buffer, length); // initiate the write

  // Write the stop time out to the chip. This is the time when the chip will
  //  generate a low output. The value is in units of 1.2us. 1.5ms corresponds
  //  to "neutral" position. This is where the value 1250 below comes
  //  from.

  buffer[0] = 0x08;   // "stop time" reg for channel 0
  buffer[1] = 1250 & 0xff; // The "low" byte comes first...
  buffer[2] = (1250>>8) & 0xff; // followed by the high byte.
  write(file_i2c, buffer, length); // Initiate the write.

  usleep(2000000); // sleep for 2s.

  // Write stop time again. Don't need to write start time again because we
  //  start time can always be left as zero. 836 corresponds to 1ms time,
  //  which is 90 degrees offset from neutral.
 
  buffer[0] = 0x08;   // "stop time" reg for channel 0
  buffer[1] = 836 & 0xff; // The "low" byte comes first...
  buffer[2] = (836>>8) & 0xff; // followed by the high byte.
  write(file_i2c, buffer, length); // Initiate the write.

  usleep(2000000);

  // Write stop time again. 1664 is 2ms, or 90 degrees offset from neutral in
  //  the opposite direction.
  buffer[0] = 0x08;   // "stop time" reg for channel 0
  buffer[1] = 1664 & 0xff; // The "low" byte comes first...
  buffer[2] = (1664>>8) & 0xff; // followed by the high byte.
  write(file_i2c, buffer, length); // Initiate the write.

  return 0;
}

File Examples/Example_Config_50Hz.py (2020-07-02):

import smbus, time
bus = smbus.SMBus(1)
addr = 0x40

## Running this program will move the servo to 0, 45, and 90 degrees with 5 second pauses in between with a 50 Hz PWM signal.

bus.write_byte_data(addr, 0, 0x20) # enable the chip
time.sleep(.25)
bus.write_byte_data(addr, 0, 0x10) # enable Prescale change as noted in the datasheet
time.sleep(.25) # delay for reset
bus.write_byte_data(addr, 0xfe, 0x79) #changes the Prescale register value for 50 Hz, using the equation in the datasheet.
bus.write_byte_data(addr, 0, 0x20) # enables the chip

time.sleep(.25)
bus.write_word_data(addr, 0x06, 0) # chl 0 start time = 0us
               
time.sleep(.25)
bus.write_word_data(addr, 0x08, 209) # chl 0 end time = 1.0ms (0 degrees)
time.sleep(.15)
bus.write_word_data(addr, 0x08, 312) # chl 0 end time = 1.5ms (45 degrees)
time.sleep(.15)
bus.write_word_data(addr, 0x08, 416) # chl 0 end time = 2.0ms (90 degrees)

while True:
     time.sleep(.5)
     bus.write_word_data(addr, 0x08, 209) # chl 0 end time = 1.0ms (0 degrees)
     time.sleep(.5)
     bus.write_word_data(addr, 0x08, 312) # chl 0 end time = 1.5ms (45 degrees)
     time.sleep(.5)
     bus.write_word_data(addr, 0x08, 209) # chl 0 end time = 1.0ms (0 degrees)
     time.sleep(.5)
     bus.write_word_data(addr, 0x08, 416) # chl 0 end time = 2.0ms (90 degrees)

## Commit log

2017-05-17 Changes based on talk with Adam
    [PI_Servo_Shield.brd, PI_Servo_Shield.sch]
2017-05-23 Changes from review feedback
    [PI_Servo_Shield.brd, PI_Servo_Shield.sch]
2017-05-24 Addressed errors from double check
    [PI_Servo_Shield.brd, PI_Servo_Shield.sch]
2017-06-15 Change version number
    [PI_Servo_Shield.brd, PI_Servo_Shield.sch]
2017-06-21 Change to v10
    [PI_Servo_Shield.brd, PI_Servo_Shield.sch]
2017-09-07 Add examples
    [13716-PI_Servo_Shield_panel.v10.brd]
2019-03-22 v20 hardwaer 99% done - still needs buzzard migration
    [PI_Servo_Shield.brd, PI_Servo_Shield.sch]
2019-03-25 Buzzard migration complete
    Also nudged some stuff to avoid silk on vias and to make room for a few labels.
    [PI_Servo_Shield.brd, PI_Servo_Shield.sch]
2019-03-25 locking fp on serial header, sch cleanup
    [PI_Servo_Shield.brd, PI_Servo_Shield.sch]
2019-03-25 adjusted I2C pullup and label
    modified sch note for bypass fuse jumper
    [PI_Servo_Shield.brd, PI_Servo_Shield.sch]
2019-03-26 post proto-design-review
    SCH cleanup:
    -3.3VA and 3.3VB combined into a single net and changed to arrow power symbol
    -5VA and 5VB combined into a single net and changed to arrow power symbol
    -added note about serial connector mating with sphero RVR
    -version to v11, will jump to v20 when going to reds
    BRD:
    -VIN ISO juper to trace closed.
    -Product Name silk updated to include "V2"
    -changed "PWR" servo rail labels to "5V"
    -corrected RX/TX swap, updated silk to RXI and TXO
    -JP2 label changed to "FUSE BP"
    -Increased 5V trace to 35 mils on connection from RVR serial header to Pi 5V pins.
    -changed version in copper to v11
    [PI_Servo_Shield.brd, PI_Servo_Shield.sch]
2019-03-27 Updated name silk label to include "V2"
    [PI_Servo_Shield.brd]
2019-03-27 post checklist changes - silk and testpoints
    -silk outlines up to 8 mil on a few.
    -testpoints
    -RX/TX LED colors corrected
    -some PROD_ID stuff fixed.
    -text note in sch for i2c jumper
    -voltage warning for > +5V RVR input damaging pi.
    [PI_Servo_Shield.brd, PI_Servo_Shield.sch]
2019-03-29 post double check stuff - moved from PCA9306 to transistors
    -PCA level shifter is EOL, moved to transistor conversion.
    -added VCC range note in SCH
    -fixed a trace off of PCA PWM chip
    -PROD_ID fixes on LEDs
    -moved measure to show units
    [PI_Servo_Shield.brd, PI_Servo_Shield.sch]
2019-04-05 Bumped the QWIIC label to 5mm package
    didn't print very cleanly at the 3mm size on the protos from jlcpcb, so bumped it up to 5mm package.
    [PI_Servo_Shield.brd, PI_Servo_Shield.sch]
2019-04-16 Added 3.3V test point - gonna need this for properly testing the CH340
    [PI_Servo_Shield.brd, PI_Servo_Shield.sch]
2019-04-16 cleaned up wire stubs
    [PI_Servo_Shield.brd]
2019-04-26 Reverse current blocking diodes and more
    -Added reverse current blocking circuits.
    -Added auto switching isolation fet between Pi 5V rail and servo rail.
    [PI_Servo_Shield.brd, PI_Servo_Shield.sch]
2019-04-29 schematic cleanup and some part positioning
    [PI_Servo_Shield.brd, PI_Servo_Shield.sch]
2019-04-30 Placed all ideal diodes and routed most things
    still need a cap and test points placed and routed.
    [PI_Servo_Shield.brd, PI_Servo_Shield.sch]
2019-05-01 V12 routed
    [PI_Servo_Shield.brd]
2019-05-01 qwiic logo line width and some final minor tweaks
    nudged pi iso jumper away to avoid polarity mark on raspi gpio header.
    approved DRC errors.
    Updated to correct width qwiic logo to avoid long cam jobs
    [PI_Servo_Shield.brd, PI_Servo_Shield.sch]
2019-05-02 Corrected package on OR gate
    [PI_Servo_Shield.brd, PI_Servo_Shield.sch]
2019-05-03 Added tRestrict around standofs as required by HAT specs
    Also moved to correct 2.5 A PTC (1812 package).
    [PI_Servo_Shield.brd, PI_Servo_Shield.sch]
2019-05-05 created python function for setting servo
    The original examples address each channel manually. I wanted a function I could call with channel and position for testing.
    While loop at bottom is good for testing each channel in sequence.
2019-05-05 final stuff during eng check for reds
    Schematic cleanup.
    Corrected OR Gate in latest library to correct SOT353 (was from older library)
    Added PROD_ID to dual PNP (TRAN-14386)
    moved some vias around to avoid cutting into silk.
    re-routed some "natural bridges" on bottom parts.
    [PI_Servo_Shield.brd, PI_Servo_Shield.sch]
2019-05-06 qc double-check changes - and SS mods
    -bumped version to v20 (was previously v12)
    -Moved bottom parts for more clearance from SS route
    [PI_Servo_Shield.brd, PI_Servo_Shield.sch]
2019-05-07 fixing DRC wire stubs, and clearance issues, ready for SS check
    [PI_Servo_Shield.brd]
2019-05-07 fixed overlap issue with trans/mosfet neat servo header
    also lead to more clearance
    [PI_Servo_Shield.brd]
2019-05-07 Fixed a couple leftover nasty traces, moved one more resistor up top for more clearance
    [PI_Servo_Shield.brd]
2019-05-07 groupd design review changes
    -changes servo rail GND silk to G (there was a resistor sitting right on top of silk - derp)
    -nudges some vias for better ground flow.
    -removed polarity mark on dual pnp package
    [PI_Servo_Shield.brd, PI_Servo_Shield.sch]
2019-05-07 fixed a non-critical "hidden" airwire within one of the huge traces.
    [PI_Servo_Shield.brd]
2019-05-08 Changed name silk label to "Pi Servo pHAT" (buzzard)
    [PI_Servo_Shield.brd]
2019-06-04 Fixed RX/TX on RVR 4-pin header
    -swapped rx/tx lines on the RVR header.
    -updated board buzzard labels on the header to reflect correction (and note, they are labeled in relation to the raspi)
    -bumped version to v21 in brd and sch
    -added RVR pin names in schematic next to 4-pin header. Put it on info layer. Just there to clarify what those pins are (in relation to the RVR).
    -moved test point (TP23) 0.05 inch east/right to gain more clarance from nearby bottom resistor (R13).
    [PI_Servo_Shield.brd, PI_Servo_Shield.sch]
2019-06-06 final changes at group review
    -added test point to pi RXI
    [PI_Servo_Shield.brd, PI_Servo_Shield.sch]
2019-06-06 Changing files names to match product name
    [Pi_Servo_pHAT.brd, Pi_Servo_pHAT.sch]
2019-06-28 Updating resistor values for LEDs
    330 for green and 1K for yellow.
    [Pi_Servo_pHAT.brd, Pi_Servo_pHAT.sch]
2019-07-11 Update: current product information
2019-07-12 Pi Servo pHAT Hookup Guide Examples
    Examples for hookup guide

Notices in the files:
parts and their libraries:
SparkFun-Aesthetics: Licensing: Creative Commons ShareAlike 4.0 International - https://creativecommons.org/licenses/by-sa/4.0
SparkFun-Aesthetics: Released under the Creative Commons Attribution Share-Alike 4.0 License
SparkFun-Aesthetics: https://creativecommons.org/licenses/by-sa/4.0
